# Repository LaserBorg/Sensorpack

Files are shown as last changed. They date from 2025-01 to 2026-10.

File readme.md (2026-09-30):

# Sensorpack

**! Work in progress !**

a Raspberry Pi Camera Array containing depth, thermal and RGB cameras.  
The device contains a Pi Pico/Pico2 to preprocess the thermal sensor data. It might also receive a BNO055 absolute orientation sensor later.

This is a personal project. I want to gain some experience with the sensors and their calibration and registration.

I used a Pi5 as host since we need two CSI-ports, but you may also be successful with a CM4 or some CSI multiplexer.

## Hardware

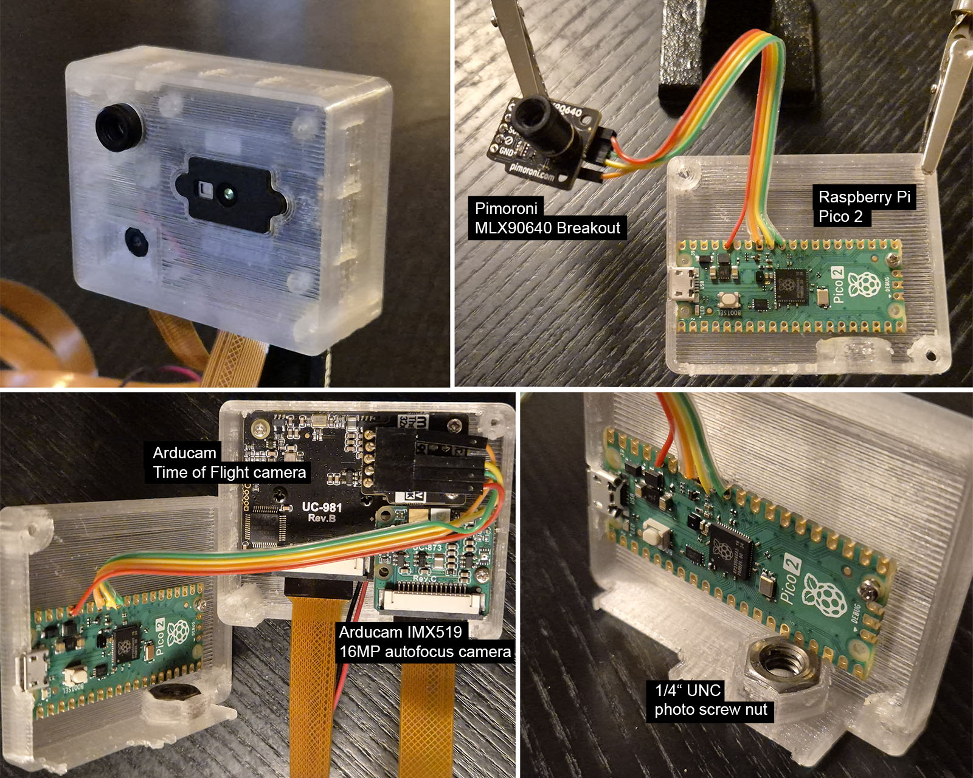
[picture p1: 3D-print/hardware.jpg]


Devices:
- Arducam ToF Camera ([info](https://www.arducam.com/time-of-flight-camera-raspberry-pi/))
- Raspberry Pi Camera Module 3 ([info](https://www.raspberrypi.com/products/raspberry-pi-camera-3/))
- Pimoroni MLX90640 Thermal Camera Breakout 55° ([shop](https://shop.pimoroni.com/products/mlx90640-thermal-camera-breakout?variant=12536948654163))
- Raspberry Pi Pico / Pico 2
- Raspberry Pi 5

The enclosure is designed in 3ds Max and printed using Prusa Slicer in PETG for durability. project (max), exports (obj) and slicer (3mf) files are included.

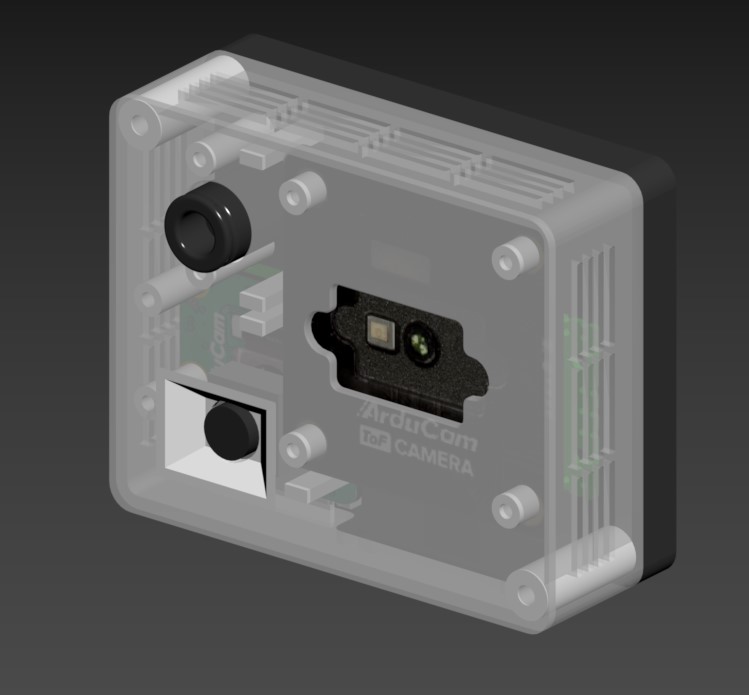
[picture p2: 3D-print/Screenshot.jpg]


## clone including submodules

```
git clone https://github.com/LaserBorg/Sensorpack.git
cd Sensorpack  
git submodule update --init --recursive
```

## build Arducam Pivariety camera driver to install the ToF camera

this was the original forum thread from April 2024 where I tried to get ToF + 16MP running with in Bookworm:  
https://forum.arducam.com/t/installation-tof-camera-fails-on-bookworm-could-not-open-device-node-dev-video0/5883/29

install the Arducam Pivariety Driver for the ToF camera as described ([troubleshooting](https://docs.arducam.com/Raspberry-Pi-Camera/Tof-camera/Troubleshooting/#4-cannot-be-used-on-raspberry-pi5)):
https://docs.arducam.com/Raspberry-Pi-Camera/Tof-camera/Getting-Started/

The RGB camera is a Raspberry Pi Camera Module 3, which is natively supported by libcamera — no extra driver needed.

With the Pi Cam 3 at CSI-0 and the ToF at CSI-1 attached, make sure your /boot/firmware/config.txt looks like this:

    dtoverlay=arducam-pivariety

I used these commands to check if the cameras are connected: 

    dmesg | grep arducam
    media-ctl -p

my ToF camera is ID 8, which is required to initialize the camera driver.

## Thermal
I modified existing implementations to send the image buffer via USB serial connection to a receiver script on the host computer. 
The submodule repo contains forks for Pico implementations running:

- Circuitpython
- Micropython
- Pico SDK
- Arduino.

Currently I'm sticking with CircuitPython, simply for ease of use.

#### Performance
Andre Weinand's [Pico SDK implementation](https://github.com/weinand/thermal-imaging-camera) provides ~ 23 fps, but unfortunately I'm not fluent with C++ and Piko SDK.

Micropython was ~4 fps and Circuitpython is even worse, so I I swapped the Pico for a Pico 2, which improved the performance a bit.

## Libcamera

some Info about Libcamera commands:
- https://www.raspberrypi.com/documentation/computers/camera_software.html

The RGB camera is a Raspberry Pi Camera Module 3 (62° FOV). It has moderate lens distortion, so it should be calibrated with a pinhole model plus distortion coefficients (`cv2.calibrateCamera`) rather than assuming an ideal pinhole.

example rpicam (= libcamera) command for a fixed exposure and gain: 

    rpicam-still --width 1920 --height 1080 --shutter 500000 --gain 2 -e png -o RGB/image.png

`python RGB/RGB-cam.py` captures three JPEGs at different shutter times with
fixed gain and white balance, then writes a floating-point Radiance `.hdr` file
to `RGB/output/`. It saves the actual exposure metadata in a `bracket_*.json`
sidecar and estimates a per-channel JPEG response curve on the first run,
reusing `RGB/output/camera_response.npz` while gain, white balance, and image
size match. Keep the scene still during the bracket. Delete the response cache
if you change camera mode, ISP processing, or JPEG settings; the existing older
JPEGs have no measured exposure metadata and cannot be merged reliably as-is.

## Open3D 

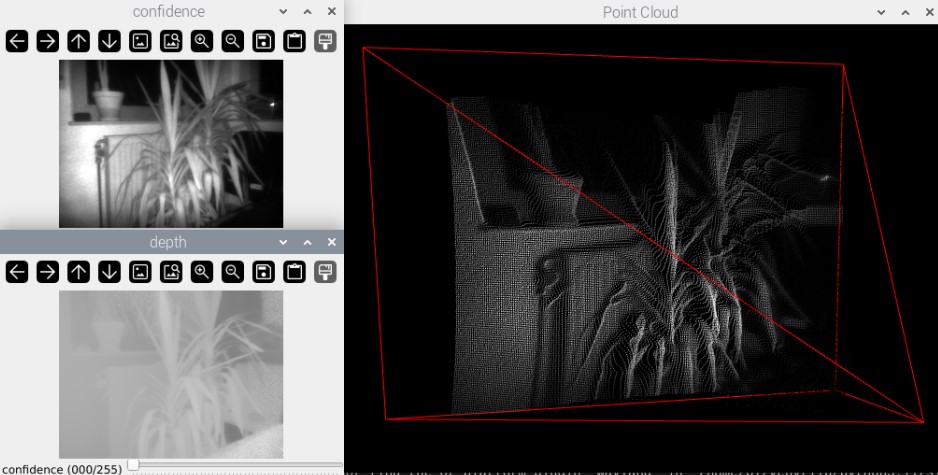
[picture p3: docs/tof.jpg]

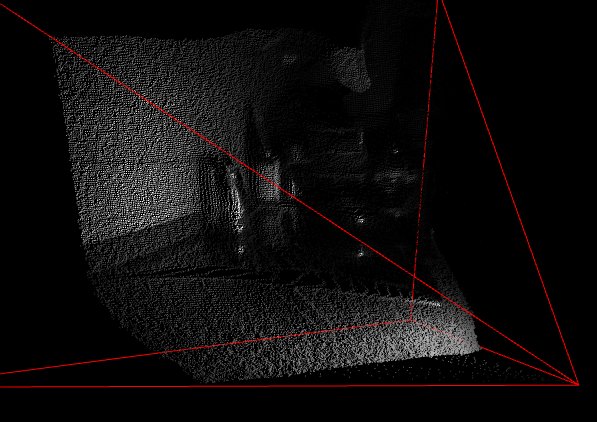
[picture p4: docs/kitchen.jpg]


#### point cloud rendering

I tried to replicate the Arducam pointcloud example (C++) using Python and used the Open3D [visualization examples](https://www.open3d.org/html/python_example/visualization/index.html) as a reference.

The depth buffer contains per-pixel **slant-range** readings (distance along each ray, in mm), not a planar z-depth. To get a proper pinhole z-depth you divide by the ray's normalized length: `z = d / sqrt(x² + y² + 1)` where `x=(u-cx)/fx`, `y=(v-cy)/fy` (see `convert_distance_to_zdepth`).

The pivariety driver exposes the camera's **firmware-calibrated intrinsics** (`INTRINSIC_FX/FY/CX/CY`, raw values are ×100), which is far more accurate than assuming a nominal FOV. `get_intrinsic_driver()` reads them directly. Note the driver does *not* return cartesian coordinates — it only gives the depth buffer plus these intrinsics, so the slant→z conversion above is still required.

#### OpenGL
because Raspberry Pi only supports OpenGL ES which seems to be not compatible to Open3D, we need to switch to software rendering:

    import os
    os.environ["LIBGL_ALWAYS_SOFTWARE"] = "1"

## Alignment

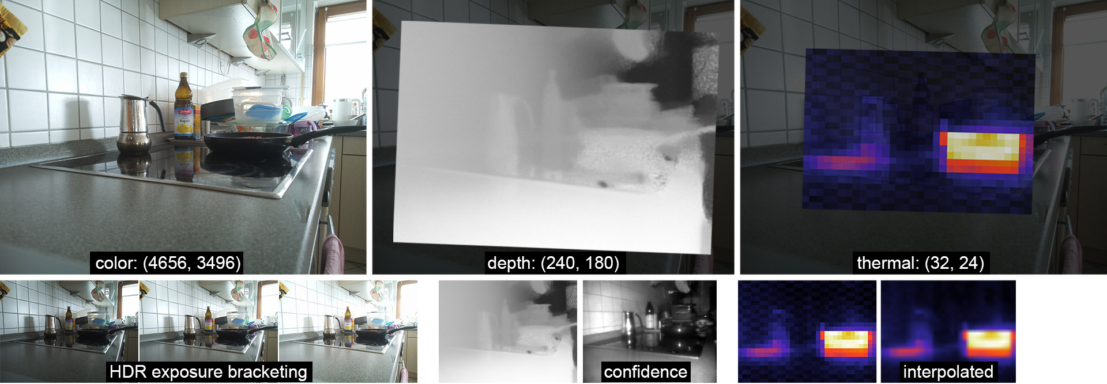
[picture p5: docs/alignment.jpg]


The active RGB/ToF calibration workflow and capture instructions are in [alignment/README.md](alignment/README.md) and [plan.md](plan.md). Because the RGB and ToF cameras are not coaxial, a single-plane homography is not enough: matched checkerboard views allow independent board poses (`cv2.solvePnP`) and a 6-DoF transform from ToF points into RGB image coordinates. Thermal registration remains future work.

## Joint Bilateral Upscaling

I plan to upscale Depth (240x180) and Thermal (32x24) data using Joint Bilateral Upscaling (JBU) with RGB as reference. It is forked from [Martin Zurowietz's](https://github.com/mzur) implementation of Johannes Kopf's [publication](https://johanneskopf.de/publications/jbu/).

the code is located in a separate repo:  
https://github.com/LaserBorg/pyJBU

I used Cython, multiprocessing and single channel kernels (instead of RGB) to significantly improve execution speed.

## BNO055 Absolute Orientation Sensor

I haven't integrated the sensor in the enclosure design yet, but a basic version of the sender code for CircuitPython (Pico) and the receiver script for the host (Pi5) is already provided for testing purposes.

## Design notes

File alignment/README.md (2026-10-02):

# Camera calibration

The active RGB/ToF workflow is in [the calibration plan](../plan.md). Work from
the repository root. `capture_calib.py` needs a Pi with both cameras and a GUI;
`calibrate_rgb.py` and `calibrate_extrinsics.py` run offline on captured images.

The printed target has **9x6 inner corners** (10x7 squares). Mount it flat and
measure the square pitch in millimeters. Keep the cameras rigidly mounted and
use the same measured `--square-size` for both calibrators:

```sh
python alignment/capture_calib.py --poses 1
# Check that the first saved RGB and ToF amplitude images show the board clearly.
python alignment/capture_calib.py --poses 24
python alignment/calibrate_rgb.py --square-size 25
python alignment/calibrate_tof.py --square-size 25
python alignment/calibrate_extrinsics.py --square-size 25
python ToF/colorize.py
```

The colorizer shows a live rolling 20-frame ToF average with the latest RGB
colors, alongside ToF depth and amplitude preview windows. In its Open3D
window, `s` saves the current cloud and RGB image, `f`
refocuses, and `q` saves the latest cloud and exits. Keep the scene stationary
over the averaging window; moving objects will blur or ghost.

Replace `25` with the measured pitch. Capture with `c`/Enter, refocus with `f`,
quit with `q`. A pose is saved only if both images contain detectable corners.
The second capture command uses the next unused pose number. Captures live in
the gitignored `img/`; the RGB and ToF intrinsic results and extrinsics are
written under `alignment/calibration/` for the colorizer to load.
Do not estimate extrinsics if the board cannot be seen in
the real ToF amplitude view. Check the reported RGB pixel RMSE and extrinsic
rotation/translation spread before trusting point colors.

For a new capture session, pass a different `--outdir` so old and new poses are
not mixed. Use that directory for `calibrate_rgb.py --input` and
`calibrate_extrinsics.py --calib-dir`. Keep the board steady for each paired shot;
the capture tool requires focused RGB and fresh RGB/ToF frames with at most
400 ms skew by default (`--max-skew-ms` adjusts the limit). Each frame must be
less than 500 ms old. A pose can still move during that interval, so a stand or
firm support is preferable to handholding. Pair latency affects extrinsics;
RGB-only reprojection RMSE reflects RGB image and corner quality, not timing
between cameras.

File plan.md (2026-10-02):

# Calibration Plan

Goal: calibrate intrinsics and extrinsics of the RGB (Pi Camera Module 3) and ToF
(Arducam pivariety) cameras so that the ToF point cloud can be colorized with RGB
values per point. Thermal (MLX90640, 32x24) is deferred to a later phase.

## Conventions

- All transforms in OpenCV camera coordinates: x right, y down, z forward.
- Units: millimeters (ToF depth buffer is in mm).
- Both cameras use the pinhole model + distortion coefficients
  (`cv2.calibrateCamera` / `cv2.solvePnP`). No fisheye model needed (62° FOV).
- The ToF depth buffer is **slant range**; convert to z-depth with
  `convert_distance_to_zdepth()` before building point clouds.

## Prerequisites

- Cameras rigidly mounted in the final enclosure (extrinsics are only valid for
  this mechanical state — recalibrate after any hardware change).
- Printed checkerboard: **9x6 inner corners** (10x7 squares). Mount it flat on a
  rigid backing. Measure the actual square pitch with calipers and pass that
  value in mm to both calibration commands; do not assume it is 25 mm.
- Keep RGB focus and capture resolution fixed after calibration. Use the same
  camera modes for calibration and colorization (2028x1520 RGB by default,
  configurable with `--rgb-size`; 240x180 ToF).
- First collect **one pilot pose** with the board fully in both views. Check
  whether its squares are distinguishable in the *real* ToF amplitude image.
  If detection fails, adjust distance, exposure/lighting and board angle before
  attempting 20-30 static paired poses spread across the shared field of view.
  Avoid motion while capturing and avoid extreme edge cropping.

## Phase 1: RGB intrinsics

Script: `alignment/calibrate_rgb.py`.

1. Capture 20-30 paired poses with `alignment/capture_calib.py` (RGB saved at
  2028x1520 by default). Save to `alignment/img/rgb/` and `alignment/img/tof/`.
2. `cv2.findChessboardCornersSB` on each RGB image; skip failed detections and
  reject mixed image sizes.
3. `cv2.calibrateCamera` → `K`, `dist`, per-view `rvecs`/`tvecs`.
4. Inspect reprojection RMSE over *all corners* (aim below ~0.5 px; check
  blurred or poorly distributed images if larger). Save `alignment/calibration/rgb_intrinsics.json`.

## Phase 2: ToF intrinsics

Script: `alignment/calibrate_tof.py`.

Calibrate from the captured ToF amplitude checkerboard images, using the same
board dimensions and measured square pitch as the RGB calibration. This writes
`alignment/calibration/tof_intrinsics.json`, including the detected image size
and board metadata. At least 10 useful views are required; use the reprojection
RMSE and corner distribution to assess the result.

1. **Distance test:** compare the median range of a flat central board patch
  with a tape measurement from near the ToF optical center at several distances;
  account for surface/lens offsets and ToF noise. Investigate a repeatable
  discrepancy before proceeding. Depth PNGs store *slant range in mm*.
2. **Corner test:** pilot-capture the ToF *amplitude* image, which is only
  240x180. The capture tool requires detection in both cameras and prints
  which view failed. A 9x6 board has only an **8x5 square pitch** between its
  outer inner corners, not the full 10x7 board width.
3. If real ToF amplitude does not resolve the grid reliably, **stop**: the
  implemented solvePnP path cannot infer ToF board corners from depth alone.
  A different detectable target or a validated depth-plane correspondence
  method would be needed before estimating extrinsics.

## Phase 3: RGB ↔ ToF extrinsics

Script: `alignment/calibrate_extrinsics.py`

1. Capture N (20-30) poses where the checkerboard is fully visible in **both**
   cameras. For each pose save a matched pair:
  - `alignment/img/rgb/pose_XX.jpg`
  - `alignment/img/tof/pose_XX_depth.png` + `pose_XX_amplitude.png`
   (Board static during the pair; no hardware sync needed.)
2. For each pose:
   - Detect corners in the RGB image → `solvePnP` → board pose in RGB frame
     (`T_rgb_board`).
  - Detect corners in the ToF amplitude image → `solvePnP`
     → board pose in ToF frame (`T_tof_board`).
3. Per-pose relative transform: `T_rgb_tof = T_rgb_board · inv(T_tof_board)`:
  `p_rgb = R · p_tof + t` (the direction used by the colorizer).
4. Average rotations with an SO(3) projection and translations with a mean;
  inspect translation and rotation spread, rejecting inconsistent board
  orientations. Re-capture poor or ambiguous poses rather than trusting an
  average over them.
5. Save to `alignment/calibration/extrinsics_rgb_tof.json` (R, t in mm, per-pose residuals).

## Phase 4: Colorized point cloud

Script: `ToF/colorize.py`

1. Autofocus RGB, then stream RGB and ToF together. Build a live point cloud
  from a rolling average of 20 ToF depth/amplitude frames (`--frames` sets
  the window size). Invalid or zero depth readings do not contribute to the
  mean. Keep the scene still over the averaging window to avoid ghosting.
2. For each point p (ToF camera coords):
   - `p_rgb = R · p + t` → undistort the RGB frame, project with its new K and
     bilinearly sample. Points outside the RGB image or behind the camera get
     no color. Calibrated RGB resolution must match the capture mode.
3. Assign per-point color, render/save PLY.
4. **Validation:** point cloud of the checkerboard should show a clean,
   undistorted grid; straight edges in the scene should stay straight.
  Press `s` in the Open3D window to save the current colored cloud and RGB
  frame, `f` to refocus, or `q` to save the latest cloud and exit.

## Phase 5 (later): Thermal

- Thermal intrinsics are hard at 32x24. Preferred: calibrate thermal ↔ RGB
  extrinsics from checkerboard poses (reuse RGB intrinsics for projection),
  or thermal ↔ ToF the same way as Phase 3.
- Then assign thermal values per point via nearest-neighbor lookup in the
  32x24 grid (blocky result is inherent to the sensor).

## Deliverables

| File | Content |
|---|---|
| `alignment/calibration/rgb_intrinsics.json` | K, dist, image size, reprojection error |
| `alignment/calibration/tof_intrinsics.json` | Firmware K, image size, distortion assumption |
| `alignment/calibration/extrinsics_rgb_tof.json` | R, t (mm), per-pose residuals |
| `alignment/calibrate_rgb.py` | Phase 1 script |
| `alignment/calibrate_extrinsics.py` | Phase 3 script |
| `ToF/colorize.py` | Phase 4 script |

## Before Capturing

1. Measure the printed squares; keep the board flat and the camera rig fixed.
2. Run `python alignment/capture_calib.py --poses 1`. Hold the board still and
  press `c` in the preview. A failed detection is not saved. Inspect the saved
  RGB, amplitude and depth files before collecting the remaining 20-30 poses.
3. Run `python alignment/capture_calib.py --poses 24` (it resumes at unused
  pose numbers), then `python alignment/calibrate_rgb.py --square-size MM` and
  `python alignment/calibrate_extrinsics.py --square-size MM` using the same
  measured pitch for both commands. Inspect RMSE and transform spread before
  `python ToF/colorize.py`. Never reuse extrinsics after moving either camera.

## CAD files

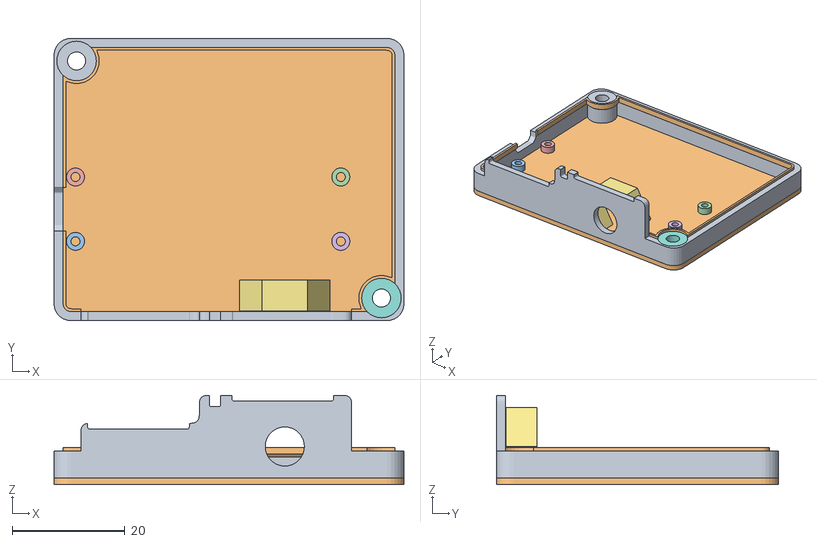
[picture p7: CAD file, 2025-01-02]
3D-print/export/sensorpack_back.obj
62.0 x 50.0 x 15.8
case_wall002
case_front001
Tube007
Tube006
Tube005
Tube008
Tube009
Tube010

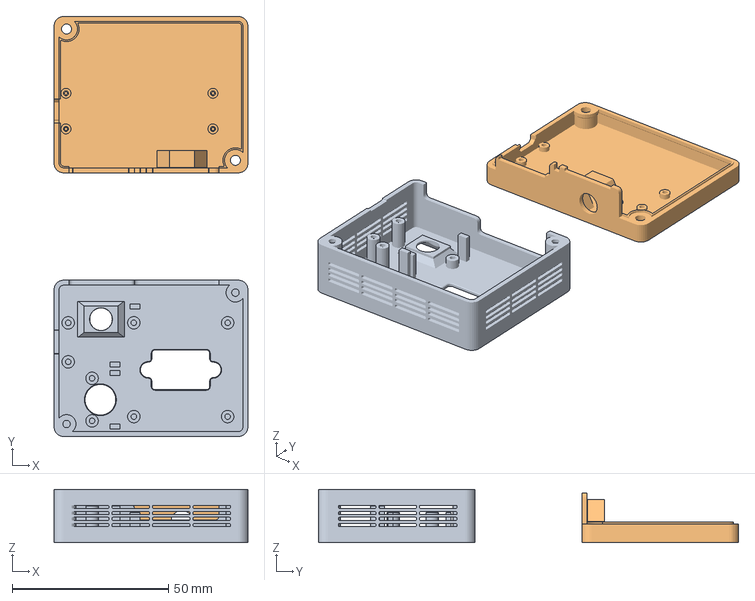
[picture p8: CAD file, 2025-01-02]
3D-print/sensorpack.3mf
62.0 x 134.3 x 17.0 mm
sensorpack_front.obj
sensorpack_back.obj

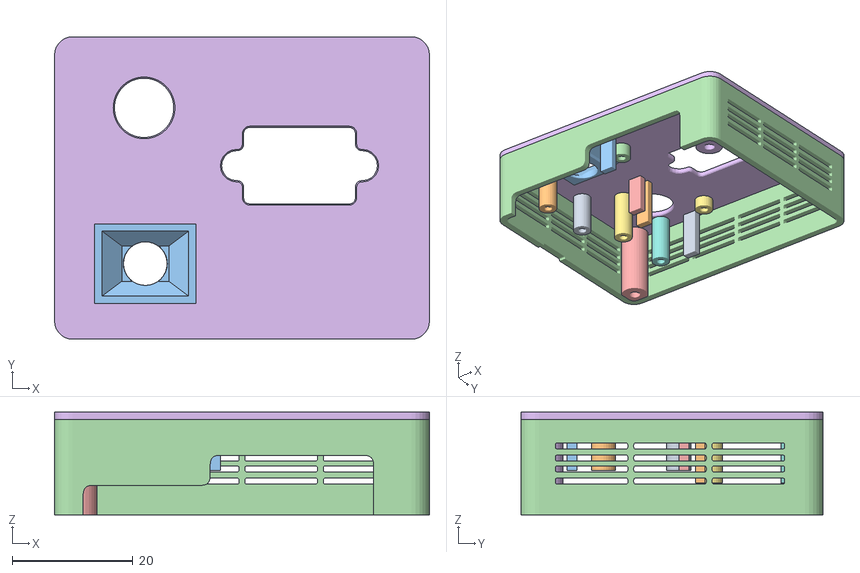
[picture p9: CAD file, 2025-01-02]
3D-print/export/sensorpack_front.obj
62.0 x 50.0 x 17.0
Circle005
Circle008
Circle003
case_front
Circle009
Circle010
cam_schacht
case_wall001
Tube001
Tube002
Circle004
Circle002
Circle001

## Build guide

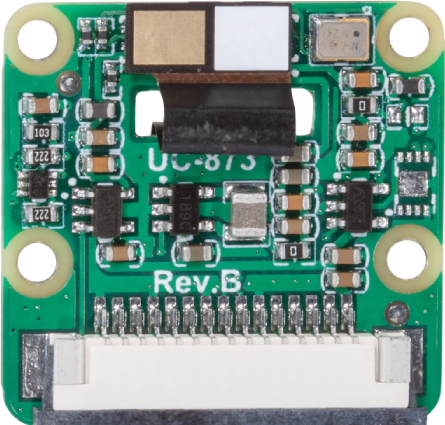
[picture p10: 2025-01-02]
3D-print/textures/imx519_back.jpg

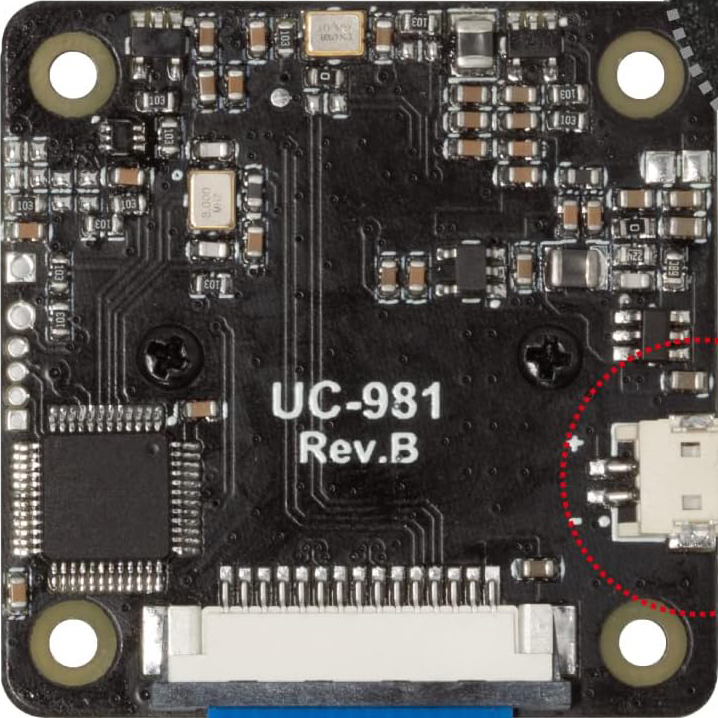
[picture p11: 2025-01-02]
3D-print/textures/tof_back.jpg

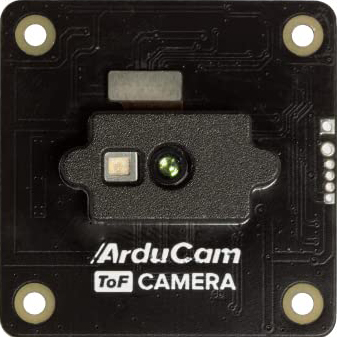
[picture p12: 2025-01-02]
3D-print/textures/tof_front.jpg

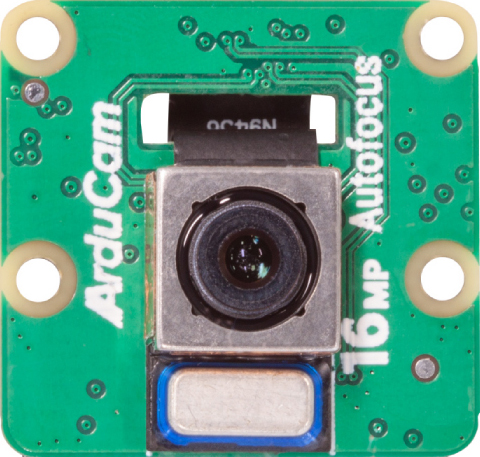
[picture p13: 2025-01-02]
3D-print/textures/im519_front.jpg

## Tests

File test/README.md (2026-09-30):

# Tests

Run from the repository root with the project virtual environment:

```sh
/home/pi/venv/bin/python -m unittest discover -s test -p 'test_*.py' -v
```

`test_colorize.py` exercises the live colorizer without opening either camera
or an Open3D window. Fake frames check that the rolling ToF window ignores
invalid depth, evicts its oldest frame, and releases driver frames. A fake
viewer and RGB/ToF cameras check frustum-first initialization, repeated point
cloud updates, saving the latest result on exit, and closing both cameras. It does not verify
autofocus quality, frame rate, or rendering on the physical rig.

`test_rgb_hdr.py` uses a fake Picamera2 to check fixed-gain shutter bracketing,
locked auto controls, and per-shot metadata recording. It also merges synthetic
JPEG brackets into a floating-point `.hdr` file and checks response-curve reuse.
It does not measure the real camera's exposure or ISP response.

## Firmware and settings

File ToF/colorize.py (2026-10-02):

'''
Continuously colorize a rolling average of ToF frames with live RGB.
Press s to save the current cloud and RGB image, f to refocus, or q to quit.
The latest cloud is also saved on exit. Keep the scene still while averaging.

Usage:
    python ToF/colorize.py [--rgb-id 0] [--tof-id 8] [--frames 20] [--save ToF/output/pcd_colorized.ply]
'''

import argparse
from collections import deque
import os
import threading

import cv2
import numpy as np
import open3d as o3d
from picamera2 import Picamera2

import sys
sys.path.insert(0, os.path.dirname(__file__))
from lib.depth_utils import (  # noqa: E402
    get_intrinsic_driver, convert_distance_to_zdepth, create_rgbd,
    filter_by_luminance, create_visualizer, apply_default_view, create_frustum,
)

import ArducamDepthCamera as ac  # noqa: E402

os.environ["LIBGL_ALWAYS_SOFTWARE"] = "1"

ALIGN_DIR = os.path.join(os.path.dirname(__file__), "..", "alignment", "calibration")


def load_calibration():
    import json
    with open(os.path.join(ALIGN_DIR, "rgb_intrinsics.json")) as f:
        rgb = json.load(f)
    with open(os.path.join(ALIGN_DIR, "tof_intrinsics.json")) as f:
        tof = json.load(f)
    with open(os.path.join(ALIGN_DIR, "extrinsics_rgb_tof.json")) as f:
        ext = json.load(f)

    K_rgb = np.array(rgb["camera_matrix"], dtype=np.float64)
    dist_rgb = np.array(rgb["distortion_coefficients"], dtype=np.float64)
    K_tof = np.array(tof["camera_matrix"], dtype=np.float64)
    dist_tof = np.array(tof["distortion_coefficients"], dtype=np.float64)
    R = np.array(ext["R"], dtype=np.float64)
    t = np.array(ext["t_mm"], dtype=np.float64)
    rgb_size = (rgb["image_size"]["width"], rgb["image_size"]["height"])
    tof_size = (tof["image_size"]["width"], tof["image_size"]["height"])
    return K_rgb, dist_rgb, K_tof, dist_tof, R, t, rgb_size, tof_size


def colorize_pointcloud(pcd, rgb_image, K, R, t):
    '''Assign per-point RGB colors by projecting points into the RGB camera.

    rgb_image must be pre-undistorted and K the corresponding (new) camera matrix,
    so a plain pinhole projection is valid.
    '''
    points = np.asarray(pcd.points)  # (N, 3), ToF camera frame
    h, w = rgb_image.shape[:2]

    # transform all points into the RGB camera frame
    pts_rgb = (R @ points.T).T + t  # (N, 3) in RGB camera frame

    valid = pts_rgb[:, 2] > 10.0  # in front of the camera (>= 10mm)
    x = pts_rgb[valid, 0] / pts_rgb[valid, 2]
    y = pts_rgb[valid, 1] / pts_rgb[valid, 2]
    # ideal pinhole projection (rgb_image is pre-undistorted, so K is the new_K)
    uv = np.stack([x * K[0, 0] + K[0, 2],
                   y * K[1, 1] + K[1, 2]], axis=1)

    inside = (uv[:, 0] >= 0) & (uv[:, 0] < w) & (uv[:, 1] >= 0) & (uv[:, 1] < h)

    colors = np.zeros((len(points), 3), dtype=np.float64)
    idx = np.where(valid)[0]
    uu = uv[inside, 0].astype(np.float32)
    vv = uv[inside, 1].astype(np.float32)
    # bilinear sampling
    x0 = np.floor(uu).astype(int)
    y0 = np.floor(vv).astype(int)
    x1 = np.clip(x0 + 1, 0, w - 1)
    y1 = np.clip(y0 + 1, 0, h - 1)
    x0 = np.clip(x0, 0, w - 1)
    y0 = np.clip(y0, 0, h - 1)
    dx = (uu - x0).reshape(-1, 1)
    dy = (vv - y0).reshape(-1, 1)
    top = rgb_image[y0, x0] * (1 - dx) + rgb_image[y0, x1] * dx
    bot = rgb_image[y1, x0] * (1 - dx) + rgb_image[y1, x1] * dx
    colors[idx[inside]] = (top * (1 - dy) + bot * dy)[:, ::-1] / 255.0

    pcd.colors = o3d.utility.Vector3dVector(colors)
    return pcd


class RollingToFAverage:
    def __init__(self, frame_count):
        self.frames = deque(maxlen=frame_count)
        self.frame_count = frame_count
        self.depth_sum = None
        self.depth_count = None
        self.amplitude_sum = None

    def add(self, depth, amplitude):
        valid = np.isfinite(depth) & (depth > 0)
        depth_values = np.where(valid, depth, 0).astype(np.float64)
        amplitude_values = np.nan_to_num(amplitude, nan=0.0, posinf=0.0, neginf=0.0).astype(np.float64)
        if self.depth_sum is None:
            self.depth_sum = np.zeros_like(depth_values)
            self.depth_count = np.zeros_like(valid, dtype=np.int32)
            self.amplitude_sum = np.zeros_like(amplitude_values)
        if len(self.frames) == self.frame_count:
            old_depth, old_valid, old_amplitude = self.frames.popleft()
            self.depth_sum -= old_depth
            self.depth_count -= old_valid
            self.amplitude_sum -= old_amplitude
        self.frames.append((depth_values, valid, amplitude_values))
        self.depth_sum += depth_values
        self.depth_count += valid
        self.amplitude_sum += amplitude_values

    def mean(self):
        if len(self.frames) < self.frame_count:
            return None
        depth = np.divide(self.depth_sum, self.depth_count, out=np.zeros_like(self.depth_sum), where=self.depth_count > 0)
        return depth.astype(np.float32), (self.amplitude_sum / self.frame_count).astype(np.float32)


def read_tof_frame(cam, average):
    frame = cam.requestFrame(200)
    if frame is None or not isinstance(frame, ac.DepthData):
        return False
    try:
        average.add(frame.depth_data, frame.confidence_data)
    finally:
        cam.releaseFrame(frame)
    return True


def main():
    parser = argparse.ArgumentParser()
    parser.add_argument("--rgb-id", type=int, default=0)
    parser.add_argument("--tof-id", type=int, default=8)
    parser.add_argument("--confidence", type=int, default=20)
    parser.add_argument("--frames", type=int, default=8, help="rolling ToF frames to average (default: 20)")
    parser.add_argument("--save", default=os.path.join(os.path.dirname(__file__), "output", "pcd_colorized.ply"))
    args = parser.parse_args()
    if args.frames < 1:
        parser.error("--frames must be at least 1")

    K_rgb, dist_rgb, K_tof, dist_tof, R, t, rgb_size, tof_size = load_calibration()

    # --- stream RGB at the calibrated resolution ---
    picam2 = Picamera2(args.rgb_id)
    config = picam2.create_video_configuration({"size": rgb_size, "format": "RGB888"})
    picam2.configure(config)
    picam2.set_controls({"AfMode": 1, "AfSpeed": 1})
    rgb_path = os.path.join(os.path.dirname(__file__), "output", "colorize_rgb.jpg")
    rgb_lock = threading.Lock()
    stop_rgb = threading.Event()
    refocus_rgb = threading.Event()
    latest_rgb = [None, 0]
    rgb_error = [None]

    def rgb_worker():
        try:
            while not stop_rgb.is_set():
                if refocus_rgb.is_set():
                    refocus_rgb.clear()
                    if not picam2.autofocus_cycle(wait=True):
                        print("RGB autofocus failed; check the scene and press f to retry")
                frame = picam2.capture_array()  # RGB888 bytes are BGR for OpenCV
                with rgb_lock:
                    latest_rgb[0] = frame
                    latest_rgb[1] += 1
        except Exception as error:
            rgb_error[0] = error

    rgb_thread = None
    tof = None
    vis = None
    try:
        picam2.start()
        if not picam2.autofocus_cycle(wait=True):
            raise RuntimeError("RGB autofocus failed; check the scene and retry")
        new_K, _ = cv2.getOptimalNewCameraMatrix(K_rgb, dist_rgb, rgb_size, 0, rgb_size)
        rgb_thread = threading.Thread(target=rgb_worker, daemon=True)
        rgb_thread.start()

        tof = ac.ArducamCamera()
        ret = tof.open(ac.Connection.CSI, args.tof_id)
        if ret != 0:
            raise RuntimeError(f"Failed to open ToF camera: {ret}")
        if tof.start(ac.FrameType.DEPTH) != 0:
            raise RuntimeError("Failed to start ToF camera")
        driver_intrinsic = get_intrinsic_driver(tof)
        if (driver_intrinsic.width, driver_intrinsic.height) != tof_size:
            raise RuntimeError("ToF stream resolution differs from calibration")
        tof_new_K, _ = cv2.getOptimalNewCameraMatrix(
            K_tof, dist_tof, tof_size, 0, tof_size)
        tof_map_x, tof_map_y = cv2.initUndistortRectifyMap(
            K_tof, dist_tof, None, tof_new_K, tof_size, cv2.CV_32FC1)
        intrinsic = o3d.camera.PinholeCameraIntrinsic(
            tof_size[0], tof_size[1], tof_new_K[0, 0], tof_new_K[1, 1],
            tof_new_K[0, 2], tof_new_K[1, 2])
        max_depth = tof.getControl(ac.Control.RANGE) or 4000
        average = RollingToFAverage(args.frames)

        cv2.namedWindow("depth", cv2.WINDOW_AUTOSIZE)
        cv2.namedWindow("amplitude", cv2.WINDOW_AUTOSIZE)
        vis = create_visualizer(pointsize=1.5)
        vis.add_geometry(create_frustum())
        pcd = o3d.geometry.PointCloud()
        vis.add_geometry(pcd)
        apply_default_view(vis)
        quit_requested = [False]
        save_requested = [False]
        vis.register_key_callback(ord("q"), lambda _: quit_requested.__setitem__(0, True))
        vis.register_key_callback(ord("s"), lambda _: save_requested.__setitem__(0, True))
        vis.register_key_callback(ord("f"), lambda _: refocus_rgb.set())
        rgb_undistorted = None
        current_rgb = None
        rgb_version = 0
        missed = 0
        print("Warming up ToF; press s to save, f to refocus, q to quit")

        def save_cloud():
            if args.save and len(pcd.points):
                os.makedirs(os.path.dirname(args.save) or ".", exist_ok=True)
                os.makedirs(os.path.dirname(rgb_path), exist_ok=True)
                o3d.io.write_point_cloud(args.save, pcd, write_ascii=False)
                cv2.imwrite(rgb_path, current_rgb)
                print(f"Saved {len(pcd.points)} points to {args.save}")

        while not quit_requested[0]:
            if rgb_error[0] is not None:
                raise RuntimeError("RGB capture stopped") from rgb_error[0]
            if read_tof_frame(tof, average):
                missed = 0
            else:
                missed += 1
                if missed >= 10:
                    raise RuntimeError("ToF stream stopped providing frames")

            means = average.mean()
            with rgb_lock:
                frame, version = latest_rgb
            if means is not None and frame is not None:
                if version != rgb_version:
                    if (frame.shape[1], frame.shape[0]) != rgb_size:
                        raise RuntimeError("RGB stream resolution differs from calibration")
                    current_rgb = frame
                    rgb_undistorted = cv2.undistort(frame, K_rgb, dist_rgb, None, new_K)
                    rgb_version = version
                depth, amplitude = means
                depth = cv2.remap(depth, tof_map_x, tof_map_y, cv2.INTER_NEAREST)
                amplitude = cv2.remap(amplitude, tof_map_x, tof_map_y, cv2.INTER_NEAREST)
                zdepth = convert_distance_to_zdepth(depth, intrinsic)
                amp_clipped = np.clip(amplitude, 0, np.percentile(amplitude, 99))
                amp_norm = cv2.normalize(amp_clipped, None, 0, 255, cv2.NORM_MINMAX).astype(np.uint8)
                cv2.imshow("amplitude", amp_norm)
                depth_preview = np.clip(depth * (255.0 / max_depth), 0, 255).astype(np.uint8)
                cv2.imshow("depth", cv2.bitwise_not(depth_preview))
                rgbd_image = create_rgbd(amp_norm, zdepth)
                current_pcd = o3d.geometry.PointCloud.create_from_rgbd_image(rgbd_image, intrinsic)
                current_pcd = filter_by_luminance(current_pcd, args.confidence)
                current_pcd = colorize_pointcloud(current_pcd, rgb_undistorted, new_K, R, t)
                pcd.points = current_pcd.points
                pcd.colors = current_pcd.colors
                vis.update_geometry(pcd)

            if not vis.poll_events():
                break
            vis.update_renderer()
            if cv2.waitKey(1) & 0xFF == ord("q"):
                break
            if save_requested[0]:
                save_cloud()
                save_requested[0] = False

        save_cloud()
    finally:
        stop_rgb.set()
        if rgb_thread is not None:
            rgb_thread.join(timeout=2)
        if tof is not None:
            tof.close()
        picam2.close()
        if vis is not None:
            vis.destroy_window()
        cv2.destroyAllWindows()


if __name__ == "__main__":
    main()

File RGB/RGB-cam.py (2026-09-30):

import datetime
import json
import os
import time

import cv2
import numpy as np
from picamera2 import Picamera2, Preview

OUTPUT_DIR = os.path.join(os.path.dirname(os.path.abspath(__file__)), "output")


def merge_brackets(records, output_dir, stamp):
    images = [cv2.imread(os.path.join(output_dir, record["file"])) for record in records]
    if any(image is None for image in images):
        raise RuntimeError("Could not read all bracket JPEGs")
    if any(image.shape != images[0].shape for image in images):
        raise RuntimeError("Bracket images have different resolutions")
    gain = records[0]["analogue_gain"]
    digital_gain = records[0]["digital_gain"]
    colour_gains = np.array(records[0]["colour_gains"], dtype=np.float32)
    if any(abs(record["analogue_gain"] - gain) > 0.05 * gain or
           abs(record["digital_gain"] - digital_gain) > 0.05 * digital_gain or
           not np.allclose(record["colour_gains"], colour_gains, rtol=0.05)
           for record in records):
        raise RuntimeError("Gain or white balance changed across the bracket; cannot merge radiance")

    times = np.array([record["exposure_us"] for record in records], dtype=np.float32) * np.float32(1e-6)
    response_path = os.path.join(output_dir, "camera_response.npz")
    response = None
    if os.path.exists(response_path):
        with np.load(response_path, allow_pickle=False) as saved:
            if (saved["image_shape"].tolist() == list(images[0].shape) and
                    np.isclose(saved["analogue_gain"], gain, rtol=0.05) and
                    np.isclose(saved["digital_gain"], digital_gain, rtol=0.05) and
                    np.allclose(saved["colour_gains"], colour_gains, rtol=0.05)):
                response = saved["response"]
    if response is None:
        response = cv2.createCalibrateDebevec().process(images, times)
        np.savez(response_path, response=response, image_shape=images[0].shape,
                 analogue_gain=gain, digital_gain=digital_gain, colour_gains=colour_gains)

    hdr = cv2.createMergeDebevec().process(images, times, response)
    hdr_path = os.path.join(output_dir, f"hdr_{stamp}.hdr")
    if not cv2.imwrite(hdr_path, hdr):
        raise RuntimeError(f"Could not save HDR file: {hdr_path}")
    return hdr_path


class HDRCamera:
    def __init__(self, cam_id, fstops=2, output_dir="./"):
        self.fstops = fstops
        self.output_dir = output_dir

        self.picam2 = Picamera2(cam_id)
        self.picam2.start_preview(Preview.QTGL)

        self.preview_config = self.picam2.create_preview_configuration()
        self.picam2.configure(self.preview_config)
        self.picam2.set_controls({"AfMode": 1, "AfSpeed": 1})
        self.picam2.start()
        time.sleep(2)
        if not self.picam2.autofocus_cycle(wait=True):
            self.picam2.close()
            raise RuntimeError("RGB autofocus failed")

        self.metadata = self.picam2.capture_metadata()
        self.gain = float(self.metadata["AnalogueGain"])
        self.colour_gains = tuple(self.metadata["ColourGains"])
        self.lens_position = self.metadata.get("LensPosition")

    def get_aeb_params(self):
        shutter_us = int(self.metadata["ExposureTime"])
        if self.fstops <= 0:
            return [shutter_us]
        scale = 2 ** self.fstops
        return [max(1, round(shutter_us / scale)), shutter_us, round(shutter_us * scale)]

    def capture(self):
        os.makedirs(self.output_dir, exist_ok=True)
        stamp = datetime.datetime.now().strftime("%Y%m%d-%H%M%S")
        records = []
        for index, shutter_us in enumerate(self.get_aeb_params()):
            controls = {
                "AeEnable": False,
                "AwbEnable": False,
                "AnalogueGain": self.gain,
                "ExposureTime": shutter_us,
                "ColourGains": self.colour_gains,
                "AfMode": 0,
            }
            if self.lens_position is not None:
                controls["LensPosition"] = self.lens_position
            config = self.picam2.create_still_configuration(controls=controls)
            request = self.picam2.switch_mode_and_capture_request(config, delay=2)
            try:
                metadata = request.get_metadata()
                actual_shutter = int(metadata["ExposureTime"])
                actual_gain = float(metadata["AnalogueGain"])
                if abs(actual_shutter - shutter_us) > 0.05 * shutter_us or abs(actual_gain - self.gain) > 0.05 * self.gain:
                    raise RuntimeError(f"Exposure was not applied: requested {shutter_us} us at gain {self.gain}, got {actual_shutter} us at gain {actual_gain}")
                if not np.allclose(metadata["ColourGains"], self.colour_gains, rtol=0.05):
                    raise RuntimeError("White balance changed during the bracket")
                filename = f"image{index}_{stamp}.jpg"
                request.save("main", os.path.join(self.output_dir, filename))
                records.append({
                    "file": filename,
                    "requested_exposure_us": shutter_us,
                    "exposure_us": actual_shutter,
                    "analogue_gain": actual_gain,
                    "digital_gain": float(metadata.get("DigitalGain", 1.0)),
                    "colour_gains": list(metadata["ColourGains"]),
                    "lens_position": metadata.get("LensPosition"),
                })
            finally:
                request.release()
            with open(os.path.join(self.output_dir, f"bracket_{stamp}.json"), "w") as file:
                json.dump(records, file, indent=2)
        if len(records) > 1:
            print(f"Saved floating-point HDR to {merge_brackets(records, self.output_dir, stamp)}")
        return records

    def close(self):
        self.picam2.close()


if __name__ == "__main__":
    output_dir = OUTPUT_DIR
    os.makedirs(output_dir, exist_ok=True)
    
    hdrcamera = HDRCamera(0, fstops=2, output_dir=output_dir)
    try:
        hdrcamera.capture()
    finally:
        hdrcamera.close()

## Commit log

2025-01-05 opencv calibration
2025-01-05 IMX519 calibration
2025-01-06 saving frames with timestamps
2026-10-02 calibration fix

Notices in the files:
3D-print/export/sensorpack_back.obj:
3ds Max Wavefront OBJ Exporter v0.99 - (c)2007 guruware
